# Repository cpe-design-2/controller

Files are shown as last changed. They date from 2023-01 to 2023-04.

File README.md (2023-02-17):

# `goco controller`



## Overview

Video game controller source code for the `goco` open-source video game Godot console.

## Details

The controller supports sending key presses using the traditional W/A/S/D button configuration for digital movement and A/B/X/Y button configuration for user action types. There are additionally two more digital buttons for HOME and PAUSE interactions. 

The controller also supports an analog input via joystick that is detected by a computer as a mouse device.

## Building

A makefile is provided to aid in common development commands.

1. Compile the source code:
```
make cc
```

2. Upload the binaries to the plugged-in Arduino Leonardo board:
```
make up
```

## Dependencies

- arduino-cli (see [getting started](https://arduino.github.io/arduino-cli/0.29/getting-started/) for initial setup)
- GNU Make

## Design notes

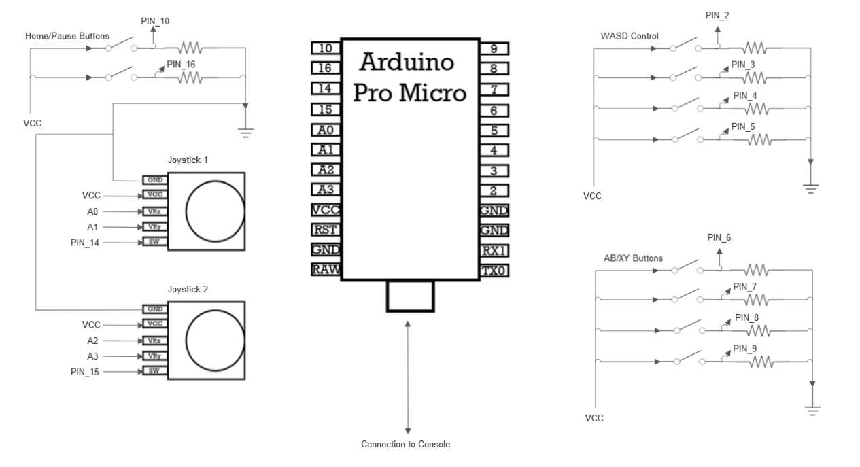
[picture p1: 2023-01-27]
docs/ControllerSchematic.PNG

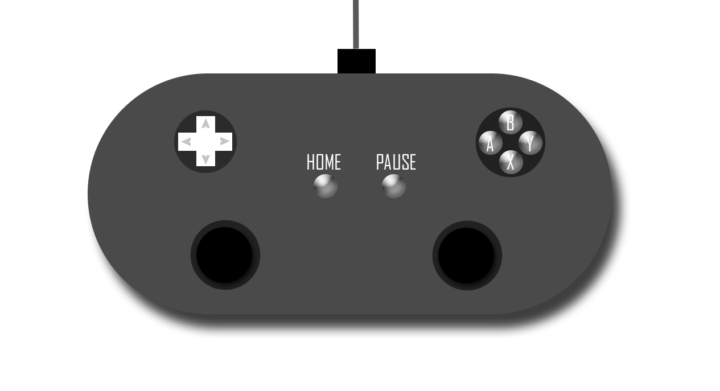
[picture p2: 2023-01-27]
docs/ControllerImage.png

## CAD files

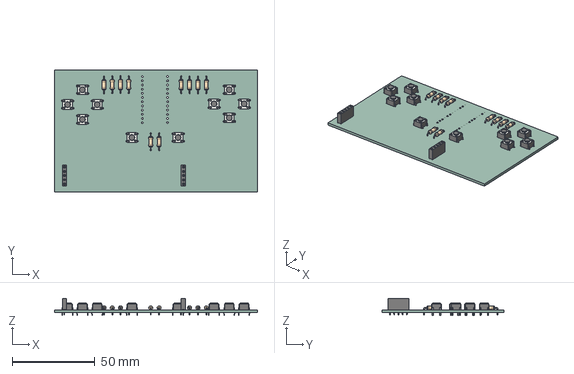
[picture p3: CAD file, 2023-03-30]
design/controller.step
123.0 x 74.0 x 10.5 mm
PCB

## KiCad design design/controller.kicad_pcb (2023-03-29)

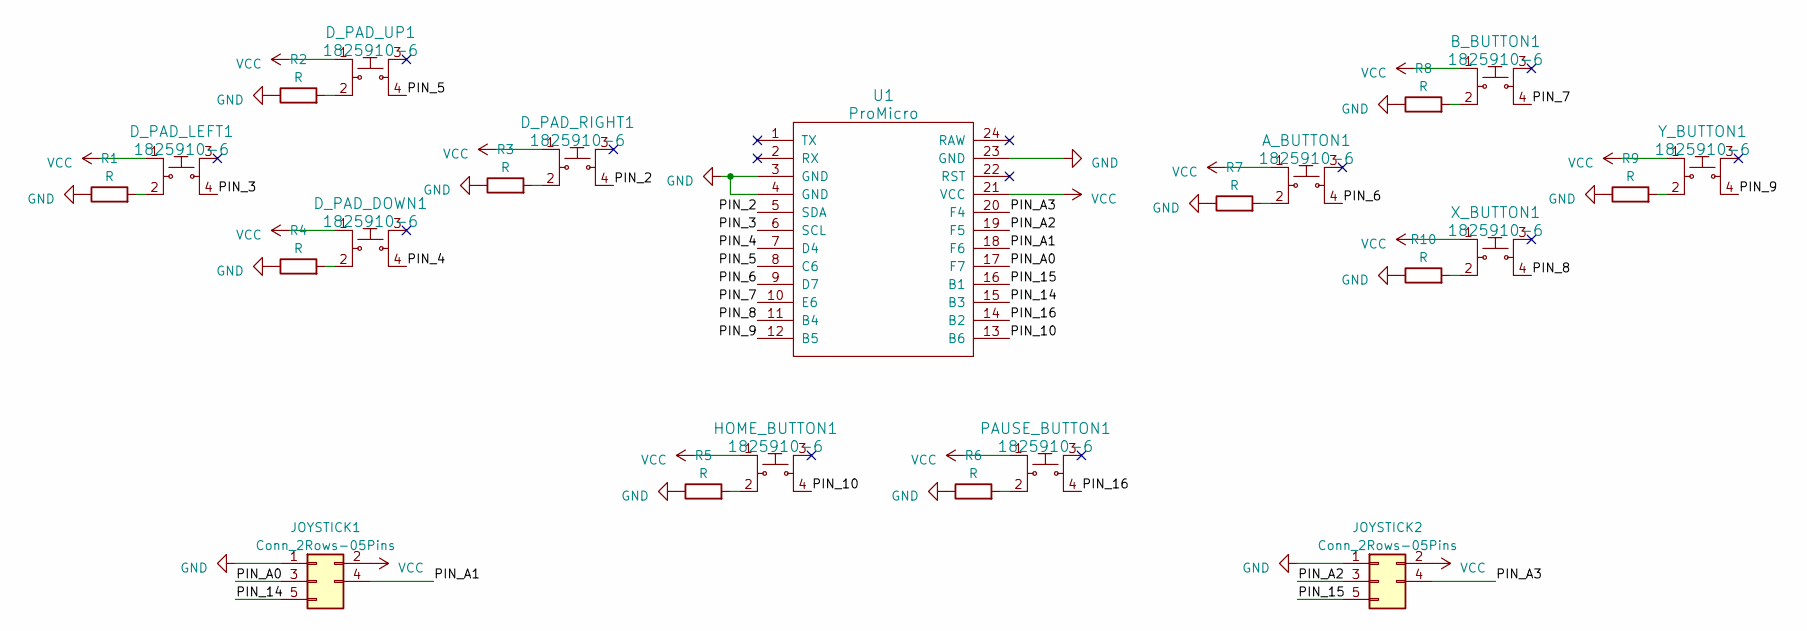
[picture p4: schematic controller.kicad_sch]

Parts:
A_BUTTON1: 1825910-6; SW_PUSH_4_PIN; MPN 1825910-6; Digi-Key_PN 450-1650-ND
B_BUTTON1: 1825910-6; SW_PUSH_4_PIN; MPN 1825910-6; Digi-Key_PN 450-1650-ND
D_PAD_DOWN1: 1825910-6; SW_PUSH_4_PIN; MPN 1825910-6; Digi-Key_PN 450-1650-ND
D_PAD_LEFT1: 1825910-6; SW_PUSH_4_PIN; MPN 1825910-6; Digi-Key_PN 450-1650-ND
D_PAD_RIGHT1: 1825910-6; SW_PUSH_4_PIN; MPN 1825910-6; Digi-Key_PN 450-1650-ND
D_PAD_UP1: 1825910-6; SW_PUSH_4_PIN; MPN 1825910-6; Digi-Key_PN 450-1650-ND
HOME_BUTTON1: 1825910-6; SW_PUSH_4_PIN; MPN 1825910-6; Digi-Key_PN 450-1650-ND
JOYSTICK1, JOYSTICK2: Conn_2Rows-05Pins; PinSocket_1x05_P2.54mm_Vertical
PAUSE_BUTTON1: 1825910-6; SW_PUSH_4_PIN; MPN 1825910-6; Digi-Key_PN 450-1650-ND
R1, R2, R3, R4, R5, R6, R7, R8, R9, R10: R; R_Axial_DIN0207_L6.3mm_D2.5mm_P10.16mm_Horizontal
U1: ProMicro
X_BUTTON1: 1825910-6; SW_PUSH_4_PIN; MPN 1825910-6; Digi-Key_PN 450-1650-ND
Y_BUTTON1: 1825910-6; SW_PUSH_4_PIN; MPN 1825910-6; Digi-Key_PN 450-1650-ND

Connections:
/PIN_2: D_PAD_RIGHT1.4, U1.5 (SDA)
/PIN_3: D_PAD_LEFT1.4, U1.6 (SCL)
/PIN_4: D_PAD_DOWN1.4, U1.7 (D4)
/PIN_5: D_PAD_UP1.4, U1.8 (C6)
/PIN_6: A_BUTTON1.4, U1.9 (D7)
/PIN_7: B_BUTTON1.4, U1.10 (E6)
/PIN_8: U1.11 (B4), X_BUTTON1.4
/PIN_9: U1.12 (B5), Y_BUTTON1.4
/PIN_10: HOME_BUTTON1.4, U1.13 (B6)
/PIN_14: JOYSTICK1.5, U1.15 (B3)
/PIN_15: JOYSTICK2.5, U1.16 (B1)
/PIN_16: PAUSE_BUTTON1.4, U1.14 (B2)
/PIN_A0: JOYSTICK1.3, U1.17 (F7)
/PIN_A1: JOYSTICK1.4, U1.18 (F6)
/PIN_A2: JOYSTICK2.3, U1.19 (F5)
/PIN_A3: JOYSTICK2.4, U1.20 (F4)
GND: JOYSTICK1.1, JOYSTICK2.1, R1.1, R2.1, R3.1, R4.1, R5.1, R6.1, R7.1, R8.1, R9.1, R10.1, U1.3 (GND), U1.4 (GND), U1.23 (GND)
unnamed: A_BUTTON1.2, R7.2
unnamed: B_BUTTON1.2, R8.2
unnamed: D_PAD_DOWN1.2, R4.2
unnamed: D_PAD_LEFT1.2, R1.2
unnamed: D_PAD_RIGHT1.2, R3.2
unnamed: D_PAD_UP1.2, R2.2
unnamed: HOME_BUTTON1.2, R5.2
unnamed: PAUSE_BUTTON1.2, R6.2
unnamed: R9.2, Y_BUTTON1.2
unnamed: R10.2, X_BUTTON1.2
VCC: A_BUTTON1.1, B_BUTTON1.1, D_PAD_DOWN1.1, D_PAD_LEFT1.1, D_PAD_RIGHT1.1, D_PAD_UP1.1, HOME_BUTTON1.1, JOYSTICK1.2, JOYSTICK2.2, PAUSE_BUTTON1.1, U1.21 (VCC), X_BUTTON1.1, Y_BUTTON1.1

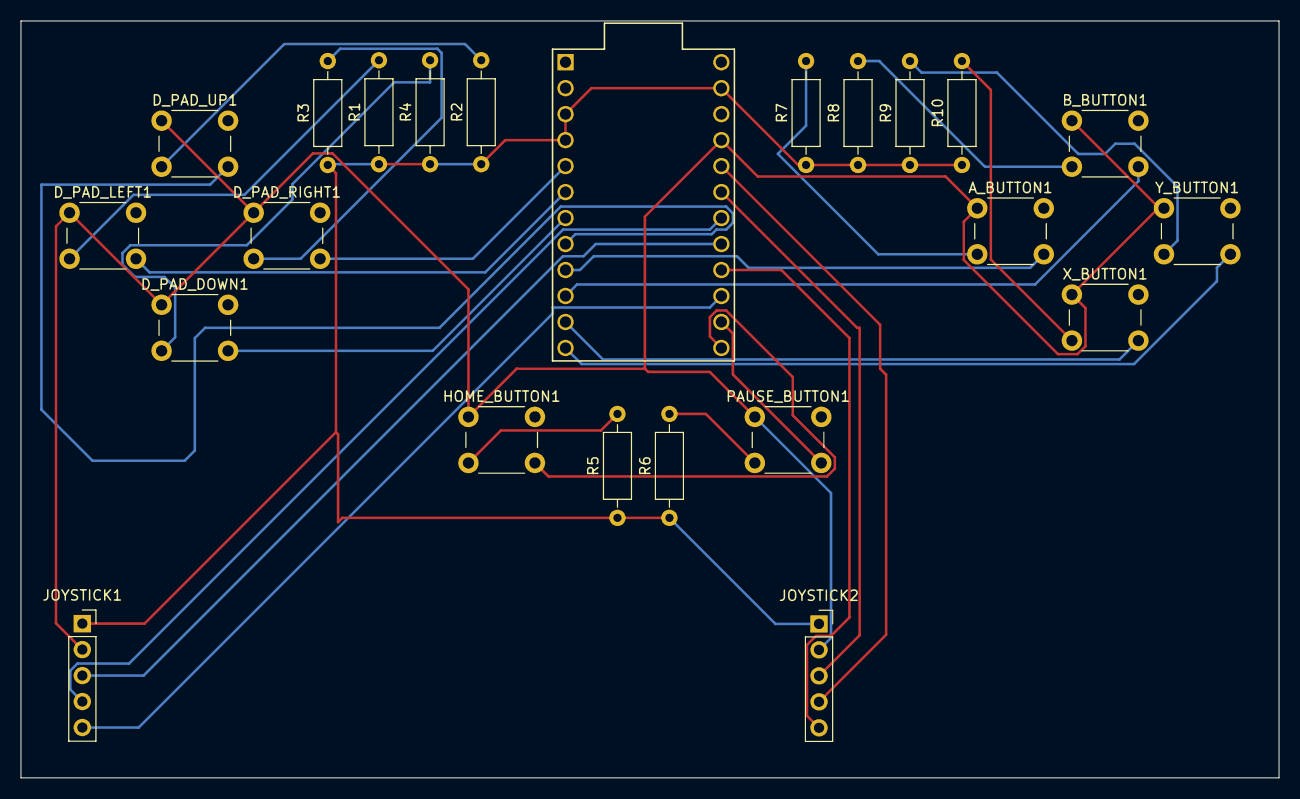
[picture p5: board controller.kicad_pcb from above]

Board: 2 copper layers, 123.0 x 74.0 mm, 23 parts (0 on the bottom side), 28 nets.

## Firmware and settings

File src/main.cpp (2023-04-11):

/*
File: main.cpp
Details:
    Entry-point to the micro-controller application.
*/

#include "arduino.h"
#include "Keyboard/src/Keyboard.h"
#include "Mouse/src/Mouse.h"
#include "Joystick/Joystick.h"

bool KEYBOARD = true;

// D-PAD/KEYBOARD CONTROL
const int UP_BUTTON    = 5;   // W (up)         
const int DOWN_BUTTON  = 4;   // S (down)       
const int LEFT_BUTTON  = 3;   // A (left)
const int RIGHT_BUTTON = 2;   // D (right)  

// BUTTON/INTERACTION CONTROL
const int A_BUTTON = 6;          
const int B_BUTTON = 7;          
const int X_BUTTON = 8;          
const int Y_BUTTON = 9; 

// HOME/PAUSE BUTTONS
const int HOME_BUTTON  = 10;         
const int PAUSE_BUTTON = 16; 

// JOYSTICK 1/MOUSE CONTROL 
const int JS_1_BUTTON = 14;  // Push button
const int JS_1_X = A0;       // X-axis
const int JS_1_Y = A1;       // Y-axis

// JOYSTICK 2 CONTROL
const int JS_2_BUTTON = 15;  // Push button
const int JS_2_X = A2;       // X-axis
const int JS_2_Y = A3;       // Y-axis       

         
// GENERAL VARIABLES
const int DELAY = 10;
const int RANGE = 12;             // output range of X or Y movement
const int THRESHOLD = RANGE / 4;  // resting threshold
const int CENTER = RANGE / 2;     // resting position value
const int MULTIPLIER = 6;         // scalar to move mouse quicker

// Function to read X and Y axis for mouse control
int readAxis(int axis){

  int read = analogRead(axis); //read the current axis
  read = map(read, 0, 1023, 0, RANGE);
  
  int to_return = (read - CENTER) * MULTIPLIER;

  if(abs(to_return) < THRESHOLD){ //don't move mouse if mouse read is too small, prevents joycon drift
    to_return = 0;
  }
  
  return to_return;
}

Joystick_ Joystick(JOYSTICK_DEFAULT_REPORT_ID,JOYSTICK_TYPE_GAMEPAD,
  12, 0,                 // Button Count, Hat Switch Count
  true, true, true,      // X and Y, but no Z Axis
  true, true, true,      // Rx, Ry, or Rz
  false, false,          // No rudder or throttle
  false, false, false);  // No accelerator, brake, or steering

void setup() {
  Serial.begin(9600);
  // if in JOYSTICK mode
  if (!KEYBOARD) { 
    /* Initialize pins */
    // D-PAD
    pinMode(UP_BUTTON, INPUT_PULLUP);
    pinMode(DOWN_BUTTON, INPUT_PULLUP);
    pinMode(LEFT_BUTTON, INPUT_PULLUP);
    pinMode(RIGHT_BUTTON, INPUT_PULLUP);

    // AB/XY
    pinMode(A_BUTTON, INPUT_PULLUP);
    pinMode(B_BUTTON, INPUT_PULLUP);
    pinMode(X_BUTTON, INPUT_PULLUP);
    pinMode(Y_BUTTON, INPUT_PULLUP);

    // PAUSE and HOME
    pinMode(HOME_BUTTON, INPUT_PULLUP);
    pinMode(PAUSE_BUTTON, INPUT_PULLUP);

    // JOYSTICK 1 control
    pinMode(JS_1_BUTTON, INPUT_PULLUP);
    pinMode(JS_1_X, INPUT);
    pinMode(JS_1_Y, INPUT);

    // JOYSTICK 2 control
    pinMode(JS_2_BUTTON, INPUT_PULLUP); 
    pinMode(JS_2_X, INPUT);
    pinMode(JS_2_Y, INPUT);

    // Initialize the Joystick library
    Joystick.begin();
    Joystick.setXAxisRange(-1, 1);
    Joystick.setYAxisRange(-1, 1);
  } else {
    //Initialize pins
    pinMode(UP_BUTTON, INPUT);
    pinMode(DOWN_BUTTON, INPUT);
    pinMode(LEFT_BUTTON, INPUT);
    pinMode(RIGHT_BUTTON, INPUT);

    pinMode(A_BUTTON, INPUT); 
    pinMode(B_BUTTON, INPUT);
    pinMode(X_BUTTON, INPUT);
    pinMode(Y_BUTTON, INPUT);         

    pinMode(HOME_BUTTON, INPUT);
    pinMode(PAUSE_BUTTON, INPUT);

    pinMode(JS_1_BUTTON, INPUT_PULLUP);
    pinMode(JS_2_BUTTON, INPUT); 

    Keyboard.begin();
    Mouse.begin();
  }
}

void loop() { 
  if (!KEYBOARD) {
    // Set the button states
    Joystick.setButton(0, digitalRead(UP_BUTTON));
    Joystick.setButton(1, digitalRead(DOWN_BUTTON));
    Joystick.setButton(2, digitalRead(LEFT_BUTTON));
    Joystick.setButton(3, digitalRead(RIGHT_BUTTON));

    Joystick.setButton(4, digitalRead(A_BUTTON));
    Joystick.setButton(5, digitalRead(B_BUTTON));
    Joystick.setButton(6, digitalRead(X_BUTTON));
    Joystick.setButton(7, digitalRead(Y_BUTTON));

    Joystick.setButton(8, digitalRead(HOME_BUTTON));
    Joystick.setButton(9, digitalRead(PAUSE_BUTTON));

    Joystick.setButton(10, !digitalRead(JS_1_BUTTON));
    Joystick.setButton(11, !digitalRead(JS_2_BUTTON));

    // Read the values from the joysticks
    int joystick_1_x = analogRead(JS_1_X);
    int joystick_1_y = analogRead(JS_1_Y);
    int joystick_2_x = analogRead(JS_2_X);
    int joystick_2_y = analogRead(JS_2_Y);

    // Convert the analog values
    int joystick_1_x_mapped = map(joystick_1_x, 0, 1023, -1, 1);
    int joystick_1_y_mapped = map(joystick_1_y, 0, 1023, -1, 1);
    int joystick_2_x_mapped = map(joystick_2_x, 0, 1023, -1, 1);
    int joystick_2_y_mapped = map(joystick_2_y, 0, 1023, -1, 1);


    // Set the values for the joystick object
    Joystick.setXAxis(joystick_1_x_mapped);
    Joystick.setYAxis(joystick_1_y_mapped);
    Joystick.setRxAxis(joystick_2_x_mapped);
    Joystick.setRyAxis(joystick_2_y_mapped);

    // Send the joystick values to the computer
    Joystick.sendState();

    // Wait for a short time before sending the next state
    delay(DELAY);
  // KEYBOARD CONFIGURATION
  } else {
    // Mouse Control:
    int x_move = readAxis(JS_1_X);
    int y_move = readAxis(JS_1_Y);

    Mouse.move(x_move, y_move, 0);  

    Serial.print(digitalRead(JS_1_BUTTON));
    
    if (digitalRead(JS_1_BUTTON) == HIGH && Mouse.isPressed(MOUSE_LEFT) == true) {
        Mouse.release(MOUSE_LEFT);
    } else if (digitalRead(JS_1_BUTTON) != HIGH && Mouse.isPressed(MOUSE_LEFT) == false) {
        Mouse.press(MOUSE_LEFT);
    }
    
    // WASD Control:
    if(digitalRead(UP_BUTTON) == HIGH){
      Keyboard.press('w');
      delay(DELAY);
    } else Keyboard.release('w');

    if(digitalRead(DOWN_BUTTON) == HIGH){
      Keyboard.press('s');
      delay(DELAY);
    } else Keyboard.release('s');

    if(digitalRead(LEFT_BUTTON) == HIGH){
      Keyboard.press('a');
      delay(DELAY);
    } else Keyboard.release('a');
    
    if(digitalRead(RIGHT_BUTTON) == HIGH){
      Keyboard.press('d');
      delay(DELAY);
    } else Keyboard.release('d');

    //spacebar control
    if(digitalRead(A_BUTTON) == HIGH){
      Keyboard.write((char) 32);
      delay(DELAY);
    }
    
    if(digitalRead(B_BUTTON) == HIGH){
      Keyboard.press('b');
      delay(DELAY);
    }

    if(digitalRead(X_BUTTON) == HIGH){
      Keyboard.press('x');
      delay(DELAY);
    }

    if(digitalRead(Y_BUTTON) == HIGH){
      Keyboard.press('Y');
      delay(DELAY);
    }

    if(digitalRead(HOME_BUTTON) == HIGH){
      Keyboard.press('h');
      delay(DELAY);
    }

    if(digitalRead(PAUSE_BUTTON) == HIGH){
      Keyboard.press('P');
      delay(DELAY);
    }

  }
}

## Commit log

2023-01-27 Controller Schematics
2023-01-27 moves schematics to docs/ folder
2023-02-11 Mouse Movement
    - Adding in Mouse Movement
    - Fixing WASD Control
    - Adding delay for de-bouncing
    [main.cpp]
2023-03-09 Adding in Kicad files
    [controller.kicad_pcb, controller.kicad_sch]
2023-03-21 Fixing controller design documents
    [controller.kicad_pcb, controller.kicad_sch]
2023-03-29 Updating Desgin Files
    Adding in Gerber files, removing unnecessary files
    [controller-B_Cu.gbr, controller-B_Mask.gbr, controller-B_Paste.gbr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]
2023-03-30 More Design File Changes
    [controller.step]
2023-04-11 fixes mouse movement and speed
    [main.cpp]

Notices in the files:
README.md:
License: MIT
